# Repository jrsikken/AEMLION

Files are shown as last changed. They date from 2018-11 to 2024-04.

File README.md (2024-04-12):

# AEMLION
This AEMLION is a 0.8x0.6 inch (20x15mm) PCB with the AEM10941 Solar Harvesting IC from E-peas. It efficiently converts solar energy into Li-ion battery charge, it even works with indoor light. It features 3.3V and 1.8V regulated outputs that are enabled when the battery has useful charge and a low battery warning that informs the user of impending shutdown when the battery runs low. It easily integrates into other projects because of small size, castellated via's, and when soldered onto 0.1" pitch header it fits in a breadboard.

I sell this board on Tindie. https://www.tindie.com/products/14711/

This project is on Hackaday https://hackaday.io/project/160376/



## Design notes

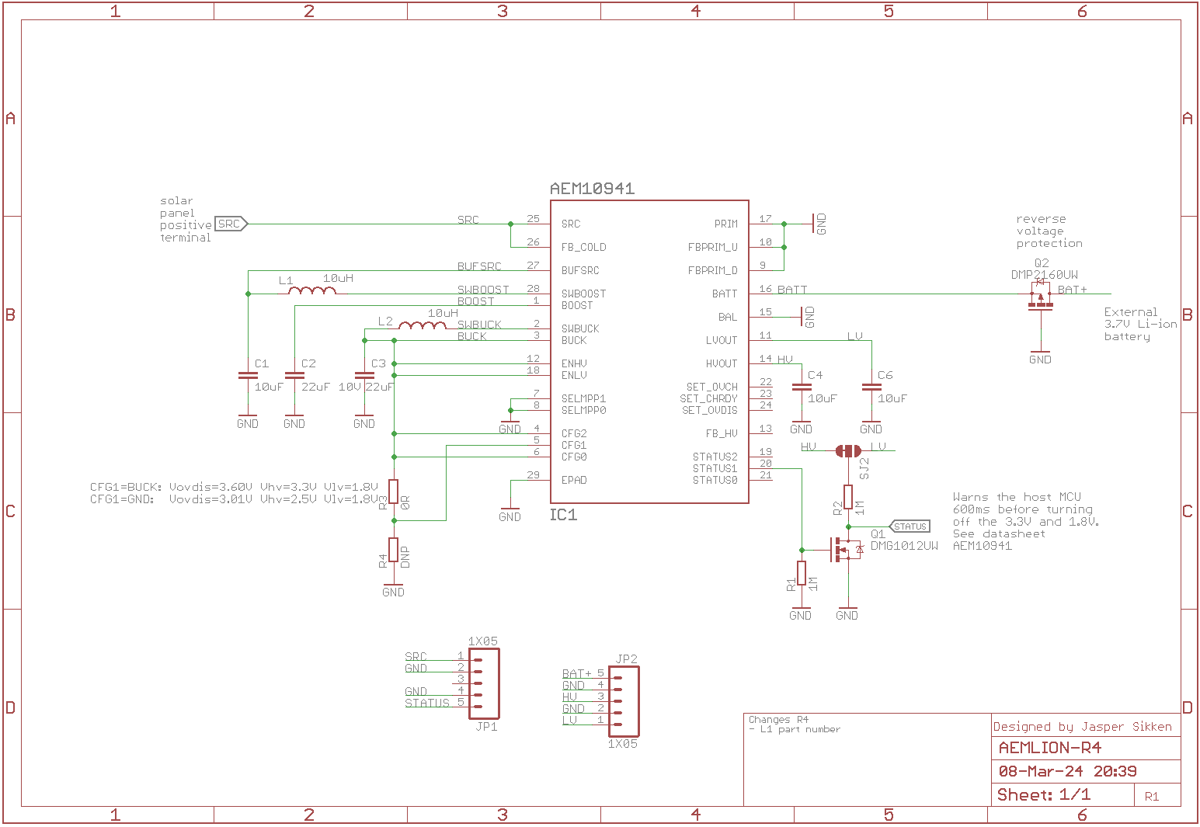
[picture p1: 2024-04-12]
AEMLION R4 schematic.png

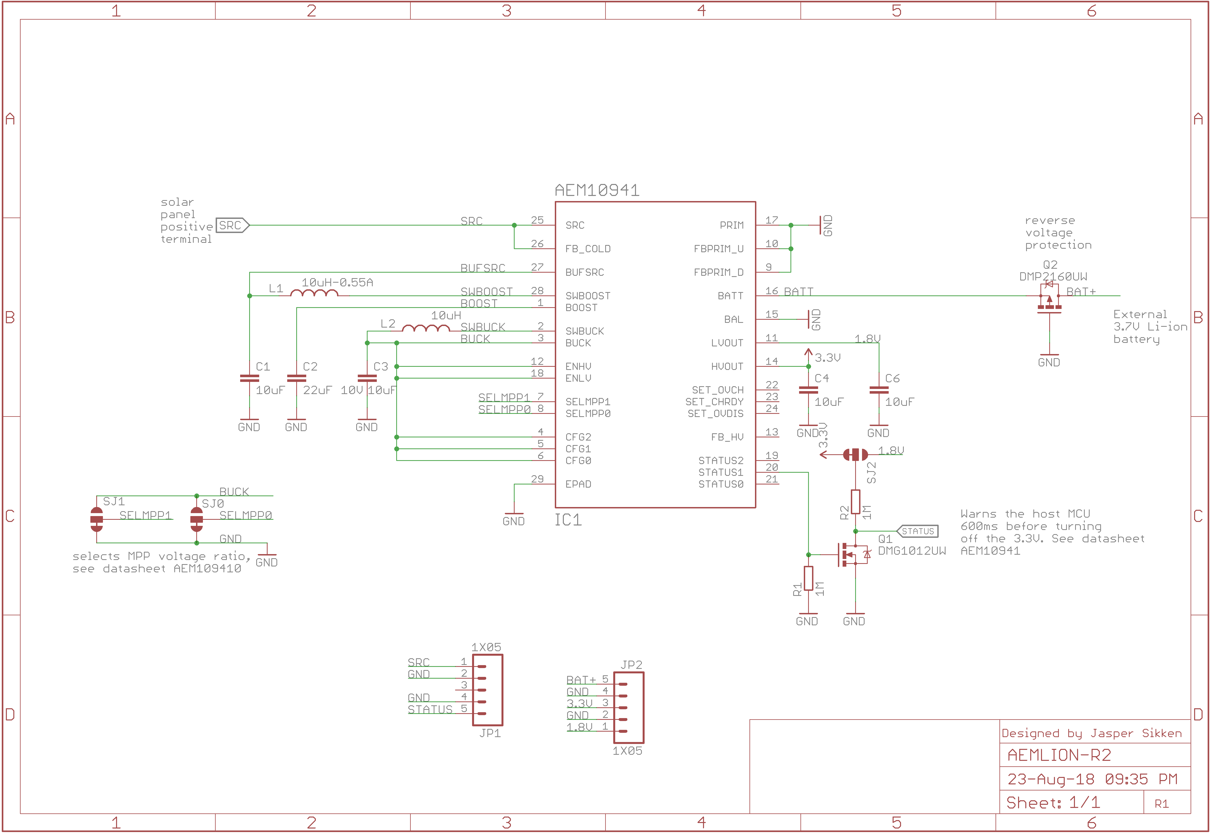
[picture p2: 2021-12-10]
AEMLION-R2-schematic.png

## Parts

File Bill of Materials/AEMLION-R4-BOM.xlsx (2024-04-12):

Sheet: PCB Specification
Your PCB Specification
PCB Quantity | 100pcs
Layer | 2layer
PCB Thickness | 1.6mm
Dimensions | 20x15mm
Castellated Hole | yes, on 2 sides
PCB Color | black
Surface Finish | HASL Lead Free
Copper Weight | 1oz
Text Color | White
Different Design | 1
Remark: Please no v-scoring on castellated holes

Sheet: BOM
AEMLION
# | Reference | QTY | Value | Package | Manufacturer | Manufacturer Part number | Description | SMD | THT | Original | Elecrow PN | Note | Voltage | Dielectric | Tolerance
1 | C1, C4, C6 | 3 | 10uF | C0603 | Generic part | Generic part | capacitor | 6 |  | N |  |  | 10V | X5R | 20%
2 | C2, C3 | 2 | 22uF | C0603 | Generic part | Generic part | capacitor | 4 |  | N |  |  | 10V | X5R | 20%
3 | L1 | 1 | 10uH | 3.25x2.5mm | Murata | DFE322512F-100M=P2 | inductor | 2 |  | Y
4 | L2 | 1 | 10uH | L0603 | TDK | MLZ1608M100WT000 | inductor | 2 |  | Y
5 | Q2 | 1 | NTS2101PT1G | SOT323 | ON Semiconductor | NTS2101PT1G | mosfet | 3 |  | Y
6 | R1, R2 | 2 | 1M | R0402 | Generic part | Generic part | resistor | 4 |  | N
7 | R3 | 1 | 0R | R0402 | Generic part | Generic part | resistor | 2 |  | N
8 | Q1 | 1 | DMG1012UW-7 | SOT323 | Diodes | DMG1012UW-7 | mosfet | 3 |  | Y
9 | IC1 | 1 | AEM10941 | QFN50P505X50 | E-peas | AEM10941 | IC | 28 |  | Y
 |  |  |  |  |  |  | total： | 54 | 0

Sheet: Position File
Designator | Footprint | Center-X(mm) | Center-Y(mm) | Layer | Rotation
C1 | C0603 | 6.23 | 7.52 | top | 90
C2 | C0603 | 6 | 3 | top | 180
C3 | C0603 | 12 | 3 | top | 0
C4 | C0603 | 15.34 | 10.13 | top | 90
C6 | C0603 | 15.36 | 7.04 | top | 270
IC1 | QFN50P505X505X90-28 | 10.7 | 7.3 | top | 90
L1 | 3.25x2.5mm | 3.6 | 7.3 | top | 270
L2 | L0603 | 9 | 3 | top | 180
Q1 | SOT323 | 17.95 | 5.5 | top | 270
Q2 | SOT323 | 6.4 | 11.6 | top | 0
R1 | R0402 | 17.52 | 7.14 | top | 180
R2 | R0402 | 18.09 | 9.6 | top | 90
R3 | R0402 | 15.37 | 2.97 | top | 270

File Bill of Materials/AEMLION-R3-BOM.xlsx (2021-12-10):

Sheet: BOM
Reference | QTY | Value | Package | Manufacturer | Manufacturer Part number | Description | Voltage | Dielectric | Tolerance
C1,C3, C4, C6 | 4 | 10uF | C0603 | Generic part | Generic part | capacitor | 10V | X5R | 20%
C2 | 1 | 22uF | C0603 | Generic part | Generic part | capacitor | 10V | X5R | 20%
L1 | 1 | 10uH-0.55A | LPS4012 | COILCRAFT | LPS4012-103MRB | inductor
L2 | 1 | 10uH | L0603 | TDK | MLZ1608M100WT000 | inductor
Q2 | 1 | NTS2101PT1G | SOT323 | ON Semiconductor | NTS2101PT1G | mosfet
R1, R2 | 2 | 1M | R0402 | Generic part | Generic part | resistor
R3 | 1 | 0R | R0402 | Generic part | Generic part | resistor
Q1 | 1 | DMG1012UW-7 | SOT323 | Diodes | DMG1012UW-7 | mosfet
IC1 | 1 | AEM10941 | QFN50P505X50 | E-peas | AEM10941 | IC

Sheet: Position File
Designator | Footprint | Center-X(mm) | Center-Y(mm) | Layer | Rotation
C1 | C0603 | 6.23 | 7.52 | top | 90
C2 | C0603 | 6 | 3 | top | 180
C3 | C0603 | 12 | 3 | top | 0
C4 | C0603 | 15.34 | 10.13 | top | 90
C6 | C0603 | 15.36 | 7.04 | top | 270
IC1 | QFN50P505X505X90-28 | 10.7 | 7.3 | top | 90
L1 | LPS4012 | 3.13 | 7.22 | top | 270
L2 | L0603 | 9 | 3 | top | 180
Q1 | SOT323 | 17.95 | 5.5 | top | 270
Q2 | SOT323 | 6.4 | 11.6 | top | 0
R1 | R0402 | 17.52 | 7.14 | top | 180
R2 | R0402 | 18.09 | 9.6 | top | 90
R3 | R0402 | 15.37 | 2.97 | top | 270

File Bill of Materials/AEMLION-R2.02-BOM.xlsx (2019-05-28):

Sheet: Bill of Materials
qty | reference designator | description | footprint | original | value | Voltage/Current | Dielectric | Tolerance | Manufacturer | MPN
4 | C1,C3, C4, C6 | capacitor | C0603 | N | 10uF | 10V | X5R | 20% | Generic part | Generic part
1 | C2 | capacitor | C0603 | N | 22uF | 10V | X5R | 5% | Generic part | Generic part
1 | L1 | inductor | LPS4012 | Y | 10uH-0.55A |  |  |  | COILCRAFT | LPS4012-103MRB
1 | L2 | inductor | L0603 | N | 10uH | 0.25A |  | 20% | COILCRAFT | LPS4012-103MRB
1 | Q2 | mosfet | SOT323 | Y | NTS2101PT1G |  |  |  | ON Semiconductor | NTS2101PT1G
2 | R1, R2 | resistor | R0402 | N | 1M |  |  | 1% | Generic part | Generic part
1 | Q1 | mosfet | SOT323 | Y | DMG1012UW-7 |  |  |  | Diodes | DMG1012UW-7
1 | IC1 | IC | QFN50P505X50 | supplied by customer | AEM10941 |  |  |  | E-peas | AEM10941

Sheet: Revision history
R2.02 | Jasper | L2 specified MF and MPN

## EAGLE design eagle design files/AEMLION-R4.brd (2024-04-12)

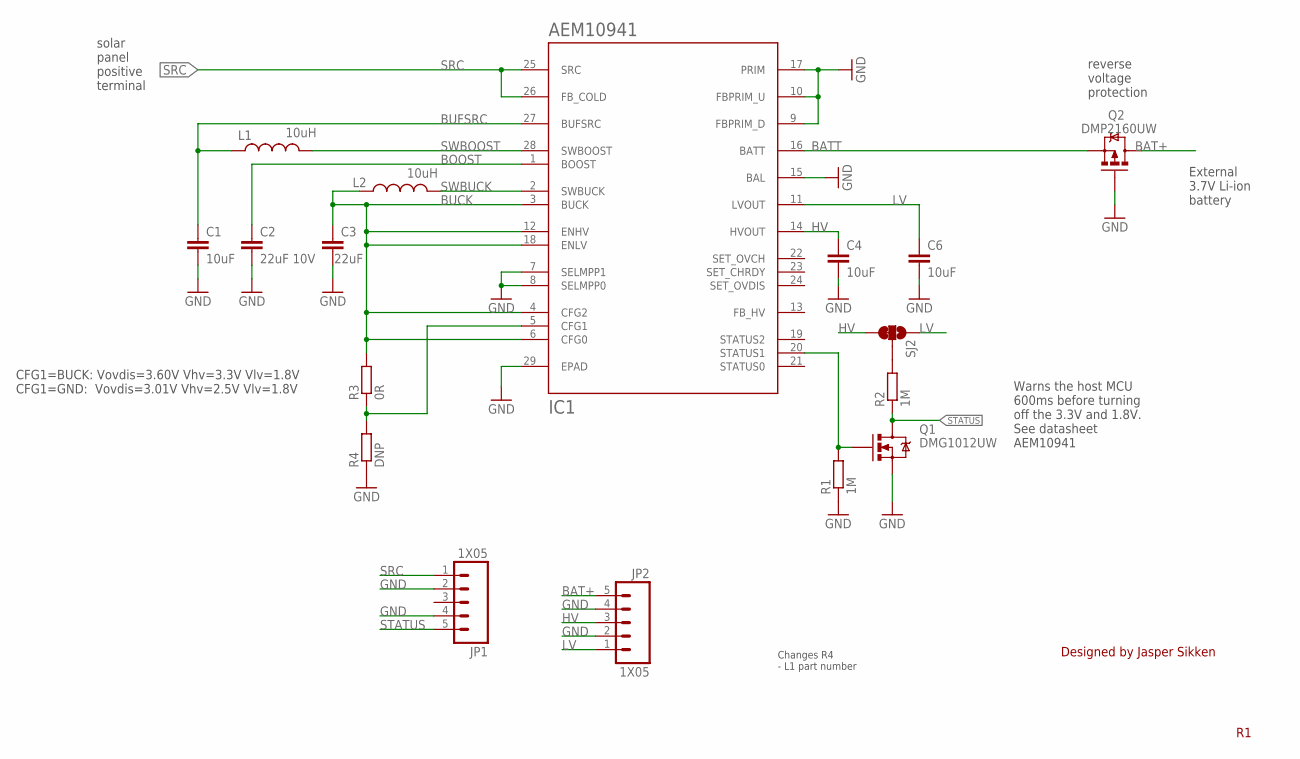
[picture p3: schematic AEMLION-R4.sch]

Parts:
C1, C4, C6: 10uF; C0603; MPN 1049P
C2: 22uF 10V; C0603; MPN CGA5L1X7S1A226M160AC
C3: 22uF; C0603; MPN 1049P
IC1: AEM10941; QFN50P505X505X90-28
JP1, JP2: 1X05; 1X05_2.54MM_ROUND_NOSILK
L1: 10uH; L_3225MM
L2: 10uH; L0603; MPN CK2125100M-T
Q1: DMG1012UW; SOT323
Q2: DMP2160UW; SOT323
R1, R2: 1M; R0402
R3: 0R; R0402
R4: DNP; R0402
SJ2: SOLDERJUMPER_3WAY_12SHORT3WAY; SJ_3S_NC_0402

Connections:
BAT+: JP2.5, Q2.3 (D)
BATT: IC1.16 (BATT), Q2.2 (S)
BOOST: C2.1, IC1.1 (BOOST)
BUCK: C3.1, IC1.3 (BUCK), IC1.4 (CFG2), IC1.6 (CFG0), IC1.12 (ENHV), IC1.18 (ENLV), L2.1, R3.2
BUFSRC: C1.1, IC1.27 (BUFSRC), L1.1
GND: C1.2, C2.2, C3.2, C4.2, C6.2, IC1.7 (SELMPP1), IC1.8 (SELMPP0), IC1.9 (FBPRIM_D), IC1.10 (FBPRIM_U), IC1.15 (BAL), IC1.17 (PRIM), IC1.29 (EPAD), JP1.2, JP1.4, JP2.2, JP2.4, Q1.2 (S), Q2.1 (G), R1.1, R4.1
HV: C4.1, IC1.14 (HVOUT), JP2.3, SJ2.1
LV: C6.1, IC1.11 (LVOUT), JP2.1, SJ2.3
unnamed: R2.2, SJ2.2
unnamed: IC1.5 (CFG1), R3.1, R4.2
SRC: IC1.25 (SRC), IC1.26 (FB_COLD), JP1.1
STATUS: JP1.5, Q1.3 (D), R2.1
STATUS1: IC1.20 (STATUS1), Q1.1 (G), R1.2
SWBOOST: IC1.28 (SWBOOST), L1.2
SWBUCK: IC1.2 (SWBUCK), L2.2

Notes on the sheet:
External 3.7V Li-ion battery
Warns the host MCU 600ms before turning off the 3.3V and 1.8V. See datasheet AEM10941
Designed by Jasper Sikken
solar panel positive terminal
reverse voltage protection
CFG1=BUCK: Vovdis=3.60V Vhv=3.3V Vlv=1.8V CFG1=GND: Vovdis=3.01V Vhv=2.5V Vlv=1.8V
Changes R4 - L1 part number

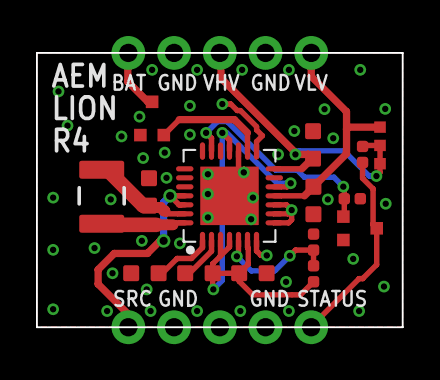
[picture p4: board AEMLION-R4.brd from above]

Board: 2 copper layers, 20.3 x 15.2 mm, 17 parts (0 on the bottom side), 15 nets.

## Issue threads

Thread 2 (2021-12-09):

R3 Design Files

birolsari, 2021-12-09:
I dont find R3 design files , How can I find it ?

jrsikken, 2021-12-10:
On https://github.com/jrsikken/AEMLION
Press the button View Code

birolsari, 2021-12-10:
I saw that but ı found just AEMLION-R2.brd board ı didnt see R3 board

jrsikken, 2021-12-10:
My bad. I will upload in 24hrs and let you know here

jrsikken, 2021-12-10:
I have uploaded R3 files

Closed 2021-12-10.

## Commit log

2018-09-09 First release
    [AEMLION-R2-BOM.xlsx, AEMLION-R2.brd, AEMLION-R2.sch]
2018-11-09 added schematic in png format
2018-11-27 Revision 2B Reduced the paste under IC1 to 50% of the exposed pad
    [AEMLION-R2.brd, AEMLION-R2.sch]
2019-05-28 specified L2 manufacturer and part number in Bill of Materials
    [AEMLION-R2.02-BOM.xlsx]
